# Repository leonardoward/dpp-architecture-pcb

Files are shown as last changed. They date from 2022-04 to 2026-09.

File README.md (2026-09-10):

# DPP Architecture Test Board v1.0

<p align="center">
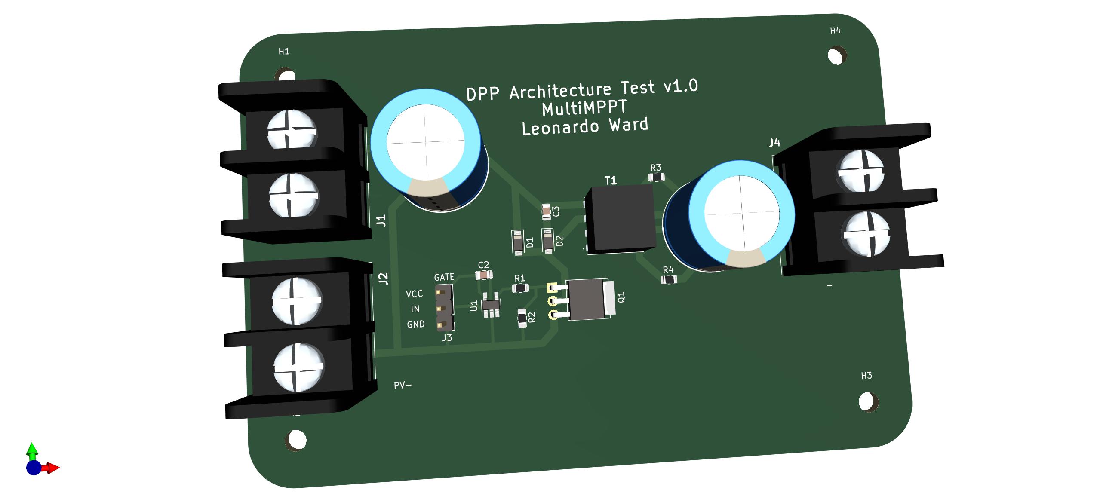
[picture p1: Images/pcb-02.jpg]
  
</p>

A single‑channel **isolated flyback power stage** on a KiCad 6 PCB, built to bench‑test
the converter used in a **Differential Power Processing (DPP)** MPPT. It is the hardware
side of the [**MultiMPPT**](https://hackaday.io/project/185092-multimppt) project &mdash; a
low‑cost, high‑efficiency MPPT with multiple independent inputs &mdash; and it implements
one converter cell from the model in
[`dpp-mppt-simulation`](https://github.com/leonardoward/dpp-mppt-simulation).

## Table of Contents

1. [What It Is](#what-it-is)
2. [How the Circuit Works](#how-the-circuit-works)
3. [Schematic](#schematic)
4. [Connectors](#connectors)
5. [Bill of Materials](#bill-of-materials)
6. [PCB](#pcb)
7. [Building the Board](#building-the-board)
8. [Repository Layout](#repository-layout)
9. [Notes & Safety](#notes--safety)
10. [License](#license)

## What It Is

In a DPP MPPT the PV modules stay in series to feed the load, and a small converter
across each module handles only the **difference** in current needed to hold that
module at its own maximum power point. This board is **one** of those converters,
broken out on its own so it can be driven, loaded and measured in isolation:

* PV / module side on `J1`, `J2`.
* String / bus side on `J4`, galvanically isolated through the transformer.
* The switching MOSFET is driven by an **external** controller (a microcontroller or a
  bench signal generator) through the 3‑pin gate‑driver header `J3` &mdash; there is no
  control loop, no sensing and no microcontroller on the board itself.

## How the Circuit Works

It is a classic isolated **flyback** converter:

1. **Input** &mdash; the module connects to `J1`/`J2`; `C1` (2200&nbsp;&micro;F) is the input
   bulk capacitor that holds the module voltage steady over a switching cycle.
2. **Switch** &mdash; `Q1` (IRFU120N N‑channel MOSFET) chops the current through the
   transformer primary. While `Q1` is on, energy is stored in the transformer core;
   when it turns off, that energy is delivered to the secondary.
3. **Gate drive** &mdash; the PWM signal enters on `J3` and is buffered by `U1`
   (DGD0215 gate driver) so the MOSFET can be switched cleanly at high frequency.
   `C2` (1&nbsp;&micro;F) decouples the driver, `R1` (1&nbsp;k) is the gate resistor and
   `R2` (100&nbsp;k) is the gate pull‑down that keeps `Q1` off when the drive is absent.
4. **Snubber / clamp** &mdash; `D1`, `D2` (1N4148W) with `C3` (47&nbsp;pF) form the
   protection network across the primary that absorbs the leakage‑inductance spike at
   turn‑off. The design allows populating either `D2 + C3` **or** `D1` alone.
5. **Transformer** &mdash; `T1` is a Würth **750311659** flyback transformer
   (180&nbsp;kHz, 1500&nbsp;Vrms primary‑to‑secondary isolation), which both transfers
   the energy and provides the galvanic isolation the DPP architecture needs.
6. **Output** &mdash; `C4` (2200&nbsp;&micro;F) filters the secondary and the converter
   output is brought out on `J4`. `R3`, `R4` are 0&nbsp;&Omega; jumpers / current‑sense
   footprints in the secondary return.

## Schematic

<p align="center">
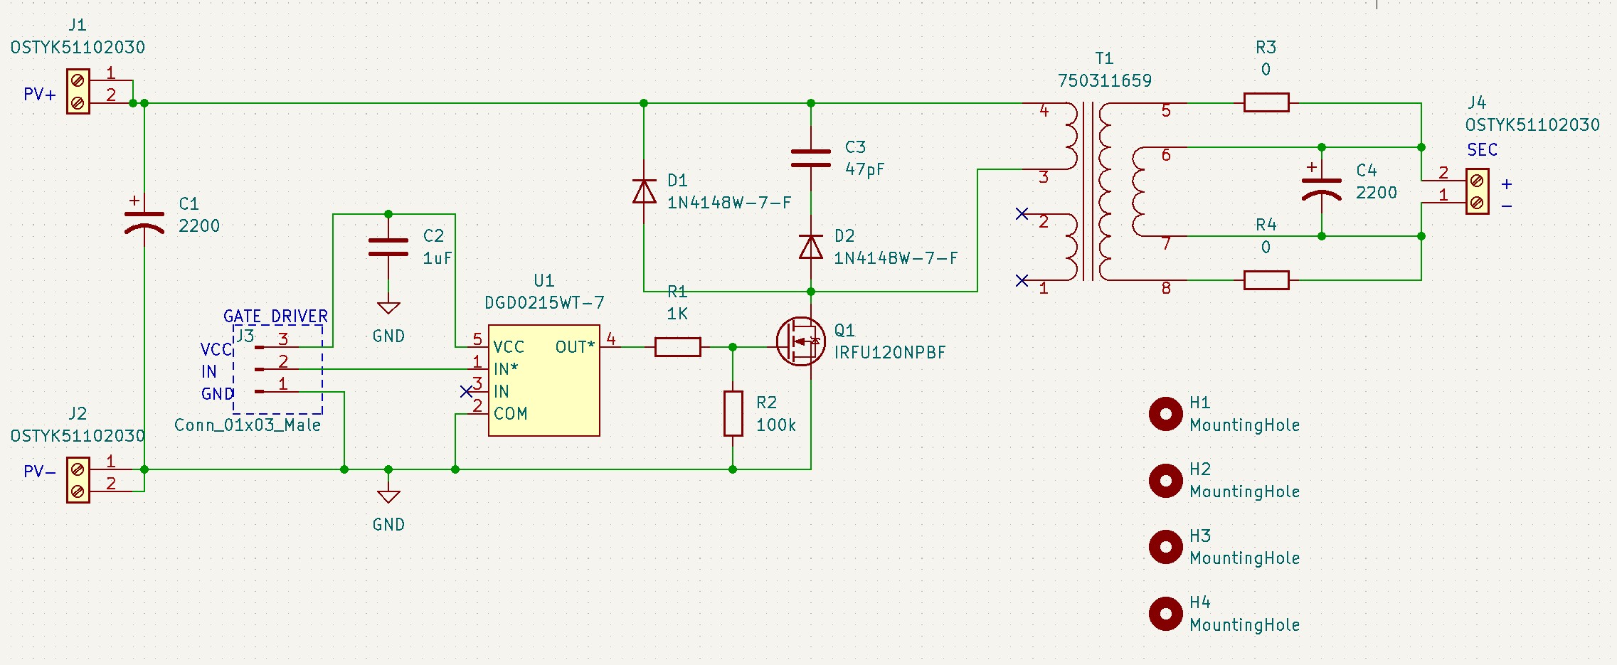
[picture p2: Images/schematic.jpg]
  
</p>

The full schematic is also in [`Schematic.pdf`](Schematic.pdf).

## Connectors

| Ref | Type | Purpose |
| --- | ---- | --- |
| `J1` | Barrier terminal block | `PV+` &mdash; module positive |
| `J2` | Barrier terminal block | `PV-` &mdash; module negative |
| `J3` | 3‑pin 0.1" header | Gate drive from the external controller: `VCC`, `IN`, `GND` |
| `J4` | Barrier terminal block | `SEC` &mdash; isolated secondary / string‑bus connection |
| `H1`&ndash;`H4` | Mounting holes | &mdash; |

## Bill of Materials

| Reference | Part | Qty |
| --- | ---- | --- |
| PCB | 2‑layer, [JLCPCB](https://jlcpcb.com/) | 1 |
| C1, C4 | 2200&nbsp;&micro;F 50&nbsp;V aluminium electrolytic, radial ([228CKS050MQW](https://www.digikey.com/en/products/detail/cornell-dubilier-illinois-capacitor/228CKS050MQW/5411846)) | 2 |
| C2 | 1&nbsp;&micro;F 25&nbsp;V X7R 0805 ([CL21B105KAFNNNE](https://www.digikey.com/en/products/detail/samsung-electro-mechanics/CL21B105KAFNNNE/3886724)) | 1 |
| C3 | 47&nbsp;pF 100&nbsp;V C0G/NP0 0805 ([08051A470JAT2A](https://www.digikey.com/en/products/detail/kyocera-avx/08051A470JAT2A/563392)) | 1 |
| D1, D2 | 100&nbsp;V 300&nbsp;mA SOD‑123 diode, 1N4148W ([1N4148W-7-F](https://www.digikey.com/en/products/detail/diodes-incorporated/1N4148W-7-F/814371)) | 2 |
| J1, J2, J4 | 9.50&nbsp;mm 2‑circuit barrier block ([OSTYK51102030](https://www.digikey.com/en/products/detail/on-shore-technology-inc/OSTYK51102030/1588818)) | 3 |
| Q1 | N‑channel 100&nbsp;V 9.4&nbsp;A IPAK / TO‑251, IRFU120N ([IRFU120NPBF](https://www.digikey.com/en/products/detail/infineon-technologies/IRFU120NPBF/812395)) | 1 |
| R1 | 1&nbsp;k&Omega; 1% 0805 ([RMCF0805FT1K00](https://www.digikey.com/en/products/detail/stackpole-electronics-inc/RMCF0805FT1K00/1760090)) | 1 |
| R2 | 100&nbsp;k&Omega; 1% 0805 ([RMCF0805FG100K](https://www.digikey.com/en/products/detail/stackpole-electronics-inc/RMCF0805FG100K/1712614)) | 1 |
| R3, R4 | 0&nbsp;&Omega; jumper 0805 ([RC0805JR-070RL](https://www.digikey.com/en/products/detail/yageo/RC0805JR-070RL/728216)) | 2 |
| T1 | Flyback transformer, 180&nbsp;kHz, 1500&nbsp;Vrms isolation, SMT ([750311659](https://www.digikey.com/en/products/detail/w%C3%BCrth-elektronik/750311659/4800066)) | 1 |
| U1 | Low‑side gate driver, inverting / non‑inverting, TSOT‑25 ([DGD0215WT-7](https://www.digikey.com/en/products/detail/diodes-incorporated/DGD0215WT-7/10130661)) | 1 |

A machine‑readable BOM is in [`dpp-architecture/dpp-architecture.csv`](dpp-architecture/dpp-architecture.csv).

## PCB

<p align="center">
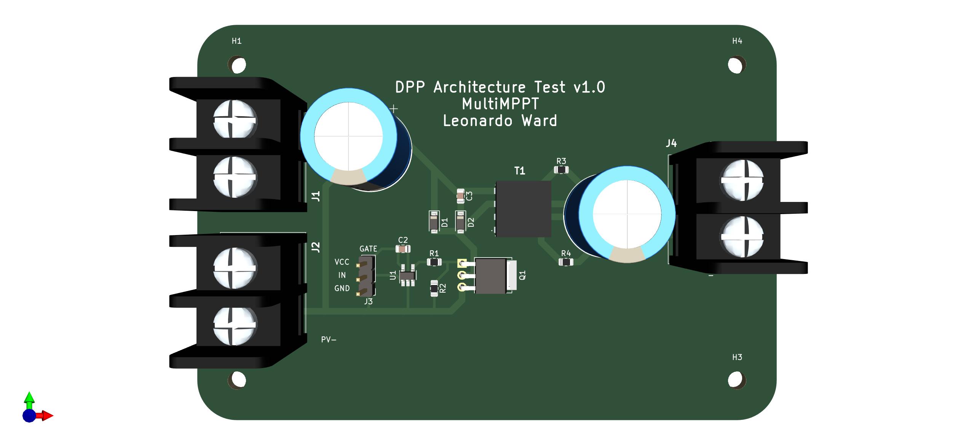
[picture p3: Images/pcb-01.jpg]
  
</p>

<p align="center">
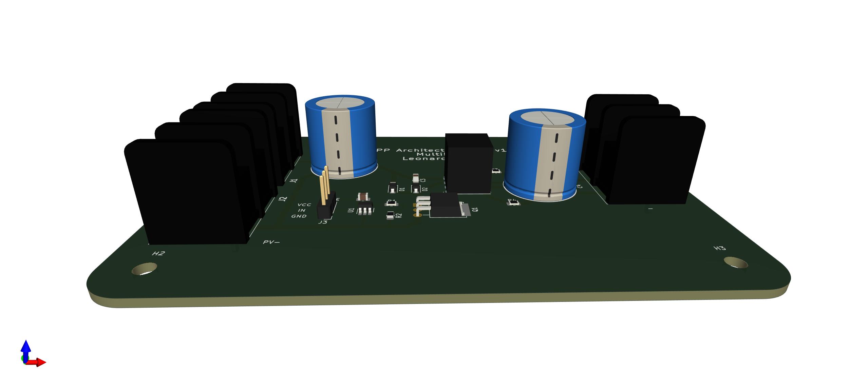
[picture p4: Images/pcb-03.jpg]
  
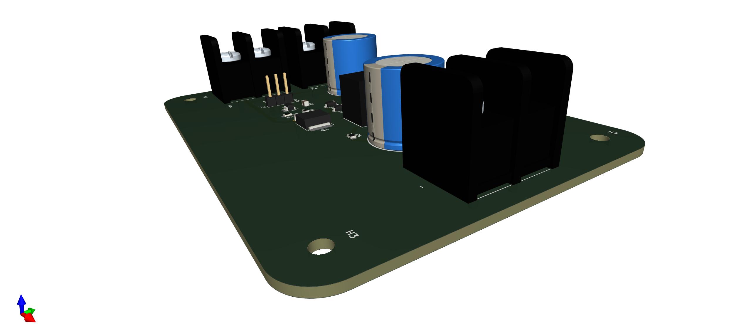
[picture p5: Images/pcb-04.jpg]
  
</p>

## Building the Board

* **Design files** &mdash; open `dpp-architecture/dpp-architecture.kicad_pro` in
  **KiCad 6** or newer. Project‑local symbol, footprint and 3D‑model libraries are
  under `dpp-architecture/Symbols/`, `dpp-architecture/Footprints/` and
  `dpp-architecture/3D/`.
* **Fabrication** &mdash; ready‑to‑send Gerbers and drill files are in
  `dpp-architecture/Gerber/` (and zipped as `dpp-architecture/Gerber.zip`); a step
  model of the assembly is in `dpp-architecture/Exports/`.

## Repository Layout

```
README.md                          this file
LICENSE                            GPL v3.0
Schematic.pdf                      exported schematic
Images/                            3D renders + schematic image for this README
dpp-architecture/
  dpp-architecture.kicad_pro/_sch/_pcb   KiCad 6 project
  dpp-architecture.csv               BOM
  Symbols/ Footprints/ 3D/           project-local libraries
  Gerber/  Gerber.zip                fabrication output
  Exports/                           STEP model of the board
  dpp-architecture-backups/          KiCad auto-save archive
```

## Notes & Safety

* This is a **v1.0 test fixture**, not a finished product: it exercises the power
  stage only. Closing the MPPT loop (sensing, duty‑cycle control) is done off‑board.
* The gate‑driver header exposes the drive rail; keep the external controller's ground
  common with `J3` `GND`.
* Electrolytic capacitors on both sides store charge &mdash; allow them to discharge
  before handling.
* The `dpp-architecture-backups/` folder is KiCad's auto‑save archive and is only kept
  for history; the working files are the ones directly under `dpp-architecture/`.

## License

Released under the **GNU General Public License v3.0** &mdash; see [`LICENSE`](LICENSE).

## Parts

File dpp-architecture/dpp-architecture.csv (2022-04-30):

Source: | /home/leonardow/Documents/dpp-architecture-pcb/dpp-architecture/dpp-architecture.kicad_sch
Date: | sáb 30 abr 2022 14:33:21
Tool: | Eeschema (6.0.4)
Generator: | /usr/share/kicad/plugins/bom_csv_grouped_by_value.py
Component Count: | 21
Individual Components:
Item | Qty | Reference(s) | Value | LibPart | Footprint | Datasheet | Description | Height | LCSC | Manufacturer | Manufacturer Part Number | Manufacturer_Name | Manufacturer_Part_Number | Supplier 1 | Supplier 2 | Supplier Part Number 1 | Supplier Part Number 2
 |  | C1 | 2200 | C-2200uF-50V-20%:2200 | Capacitor_THT:CP_Radial_D16.0mm_P7.50mm | https://www.cde.com/resources/catalogs/CKR_CKS.pdf |  |  |  |  |  | Cornell Dubilier / Illinois Capacitor | 228CKS050MQW | Digi-Key | Mouser | 228CKS050MQW-ND | 598-228CKS050MQW
 |  | C2 | 1uF | C-1uF-0805:1uF | Capacitor_SMD:C_0805_2012Metric | http://www.samsungsem.com/kr/support/product-search/mlcc/CL21B105KAFNNNE.jsp |  |  | C116352 | Samsung Electro-Mechanics | CL21B105KAFNNNE |  |  | Digi-Key | Mouser | 1276-1066-1-ND | 187-CL21B105KAFNNNE
 |  | C3 | 47pF | C-47pF-0805-100V-5%:47pF | Capacitor_SMD:C_0805_2012Metric | https://datasheets.kyocera-avx.com/C0GNP0-Dielectric.pdf |  |  |  | KYOCERA AVX |  |  | 08051A470JAT2A | Digi-Key | Mouser | 478-1282-1-ND | 581-08051A470J
 |  | C4 | 2200 | C-2200uF-50V-20%:2200 | Capacitor_THT:CP_Radial_D16.0mm_P7.50mm | https://www.cde.com/resources/catalogs/CKR_CKS.pdf |  |  |  |  |  | Cornell Dubilier / Illinois Capacitor | 228CKS050MQW | Digi-Key | Mouser | 228CKS050MQW-ND | 598-228CKS050MQW
 |  | D1 | 1N4148W-7-F | D-1N4148W-7-F:1N4148W-7-F | Diode_SMD:D_SOD-123 | https://www.diodes.com/assets/Datasheets/BAV16W_1N4148W.pdf |  |  | C83528 |  |  | Diodes Incorporated | 1N4148W-7-F | Digi-Key | Mouser | 1N4148W-FDICT-ND | 621-1N4148W-F
 |  | D2 | 1N4148W-7-F | D-1N4148W-7-F:1N4148W-7-F | Diode_SMD:D_SOD-123 | https://www.diodes.com/assets/Datasheets/BAV16W_1N4148W.pdf |  |  | C83528 |  |  | Diodes Incorporated | 1N4148W-7-F | Digi-Key | Mouser | 1N4148W-FDICT-ND | 621-1N4148W-F
 |  | H1 | MountingHole | Mechanical:MountingHole | MountingHole:MountingHole_3.5mm | ~
 |  | H2 | MountingHole | Mechanical:MountingHole | MountingHole:MountingHole_3.5mm | ~
 |  | H3 | MountingHole | Mechanical:MountingHole | MountingHole:MountingHole_3.5mm | ~
 |  | H4 | MountingHole | Mechanical:MountingHole | MountingHole:MountingHole_3.5mm | ~
 |  | J1 | OSTYK51102030 | J-OSTYK51102030:OSTYK51102030 | J-OSTYK51102030:OSTYK51102030 | https://datasheet.datasheetarchive.com/originals/distributors/Datasheets-DGA23/1525676.pdf | CONN BARRIER STRIP 2CIRC 0.374" | 18.5 |  |  |  | On Shore Technology Inc. | OSTYK51102030 | Digi-Key |  | ED2953-ND
 |  | J2 | OSTYK51102030 | J-OSTYK51102030:OSTYK51102030 | J-OSTYK51102030:OSTYK51102030 | https://datasheet.datasheetarchive.com/originals/distributors/Datasheets-DGA23/1525676.pdf | CONN BARRIER STRIP 2CIRC 0.374" | 18.5 |  |  |  | On Shore Technology Inc. | OSTYK51102030 | Digi-Key |  | ED2953-ND
 |  | J3 | Conn_01x03_Male | Connector:Conn_01x03_Male | Connector_PinHeader_2.54mm:PinHeader_1x03_P2.54mm_Vertical | ~
 |  | J4 | OSTYK51102030 | J-OSTYK51102030:OSTYK51102030 | J-OSTYK51102030:OSTYK51102030 | https://datasheet.datasheetarchive.com/originals/distributors/Datasheets-DGA23/1525676.pdf | CONN BARRIER STRIP 2CIRC 0.374" | 18.5 |  |  |  | On Shore Technology Inc. | OSTYK51102030 | Digi-Key |  | ED2953-ND
 |  | Q1 | IRFU120NPBF | Q-IRFU120NPBF:IRFU120NPBF | Package_TO_SOT_THT:TO-251-3-1EP_Horizontal_TabDown | https://www.infineon.com/dgdl/irfr120npbf.pdf?fileId=5546d462533600a40153562d2620204d |  |  | C3025 |  |  | Infineon Technologies | IRFU120NPBF | Digi-Key | Mouser | IRFU120NPBF-ND | 942-IRFU120NPBF
 |  | R1 | 1K | R-1K-0805:1K | Resistor_SMD:R_0805_2012Metric | https://www.seielect.com/catalog/sei-rmcf_rmcp.pdf |  |  |  | Stackpole Electronics Inc |  |  | RMCF0805FT1K00 | Digi-Key |  | RMCF0805FT1K00CT-ND
 |  | R2 | 100k | R-100K-0805:100k | Resistor_SMD:R_0805_2012Metric_Pad1.20x1.40mm_HandSolder | https://www.seielect.com/catalog/sei-rmcf_rmcp.pdf |  |  |  |  |  | Stackpole Electronics Inc | RMCF0805FG100K | Digi-Key |  | RMCF0805FG100KCT-ND
 |  | R3 | 0 | R-0-0805:0 | Resistor_SMD:R_0805_2012Metric | https://www.yageo.com/upload/media/product/productsearch/datasheet/rchip/PYu-RC_Group_51_RoHS_L_11.pdf |  |  |  | Yageo | RC0805JR-070RL |  |  | Digi-Key |  | 311-0.0ARCT-ND
 |  | R4 | 0 | R-0-0805:0 | Resistor_SMD:R_0805_2012Metric | https://www.yageo.com/upload/media/product/productsearch/datasheet/rchip/PYu-RC_Group_51_RoHS_L_11.pdf |  |  |  | Yageo | RC0805JR-070RL |  |  | Digi-Key |  | 311-0.0ARCT-ND
 |  | T1 | 750311659 | T-750311659:750311659 | T-750311659:750311659 | https://katalog.we-online.de/ctm/datasheet/750311659.pdf | Power Transformers MID-L8300 LT Flyback Isol .3mH 5V .08A | 10.54 |  |  |  | Wurth Elektronik | 750311659 | Digi-Key | Mouser | 1297-1126-1-ND | 710-750311659
 |  | U1 | DGD0215WT-7 | U-DGD0215WT-7:DGD0215WT-7 | Package_TO_SOT_SMD:SOT-23-5_HandSoldering | https://www.diodes.com/assets/Datasheets/DGD0215-0216.pdf |  |  |  |  |  | Diodes Incorporated | DGD0215WT-7 | Digi-Key |  | DGD0215WT-7DICT-ND
Collated Components:
Item | Qty | Reference(s) | Value | LibPart | Footprint | Datasheet | Description | Height | LCSC | Manufacturer | Manufacturer Part Number | Manufacturer_Name | Manufacturer_Part_Number | Supplier 1 | Supplier 2 | Supplier Part Number 1 | Supplier Part Number 2
1 | 2 | C1, C4 | 2200 | C-2200uF-50V-20%:2200 | Capacitor_THT:CP_Radial_D16.0mm_P7.50mm | https://www.cde.com/resources/catalogs/CKR_CKS.pdf |  |  |  |  |  | Cornell Dubilier / Illinois Capacitor | 228CKS050MQW | Digi-Key | Mouser | 228CKS050MQW-ND | 598-228CKS050MQW
2 | 1 | C2 | 1uF | C-1uF-0805:1uF | Capacitor_SMD:C_0805_2012Metric | http://www.samsungsem.com/kr/support/product-search/mlcc/CL21B105KAFNNNE.jsp |  |  | C116352 | Samsung Electro-Mechanics | CL21B105KAFNNNE |  |  | Digi-Key | Mouser | 1276-1066-1-ND | 187-CL21B105KAFNNNE
3 | 1 | C3 | 47pF | C-47pF-0805-100V-5%:47pF | Capacitor_SMD:C_0805_2012Metric | https://datasheets.kyocera-avx.com/C0GNP0-Dielectric.pdf |  |  |  | KYOCERA AVX |  |  | 08051A470JAT2A | Digi-Key | Mouser | 478-1282-1-ND | 581-08051A470J
4 | 2 | D1, D2 | 1N4148W-7-F | D-1N4148W-7-F:1N4148W-7-F | Diode_SMD:D_SOD-123 | https://www.diodes.com/assets/Datasheets/BAV16W_1N4148W.pdf |  |  | C83528 |  |  | Diodes Incorporated | 1N4148W-7-F | Digi-Key | Mouser | 1N4148W-FDICT-ND | 621-1N4148W-F
5 | 4 | H1, H2, H3, H4 | MountingHole | Mechanical:MountingHole | MountingHole:MountingHole_3.5mm | ~
6 | 3 | J1, J2, J4 | OSTYK51102030 | J-OSTYK51102030:OSTYK51102030 | J-OSTYK51102030:OSTYK51102030 | https://datasheet.datasheetarchive.com/originals/distributors/Datasheets-DGA23/1525676.pdf | CONN BARRIER STRIP 2CIRC 0.374" | 18.5 |  |  |  | On Shore Technology Inc. | OSTYK51102030 | Digi-Key |  | ED2953-ND
7 | 1 | J3 | Conn_01x03_Male | Connector:Conn_01x03_Male | Connector_PinHeader_2.54mm:PinHeader_1x03_P2.54mm_Vertical | ~
8 | 1 | Q1 | IRFU120NPBF | Q-IRFU120NPBF:IRFU120NPBF | Package_TO_SOT_THT:TO-251-3-1EP_Horizontal_TabDown | https://www.infineon.com/dgdl/irfr120npbf.pdf?fileId=5546d462533600a40153562d2620204d |  |  | C3025 |  |  | Infineon Technologies | IRFU120NPBF | Digi-Key | Mouser | IRFU120NPBF-ND | 942-IRFU120NPBF
9 | 1 | R1 | 1K | R-1K-0805:1K | Resistor_SMD:R_0805_2012Metric | https://www.seielect.com/catalog/sei-rmcf_rmcp.pdf |  |  |  | Stackpole Electronics Inc |  |  | RMCF0805FT1K00 | Digi-Key |  | RMCF0805FT1K00CT-ND
10 | 1 | R2 | 100k | R-100K-0805:100k | Resistor_SMD:R_0805_2012Metric_Pad1.20x1.40mm_HandSolder | https://www.seielect.com/catalog/sei-rmcf_rmcp.pdf |  |  |  |  |  | Stackpole Electronics Inc | RMCF0805FG100K | Digi-Key |  | RMCF0805FG100KCT-ND
11 | 2 | R3, R4 | 0 | R-0-0805:0 | Resistor_SMD:R_0805_2012Metric | https://www.yageo.com/upload/media/product/productsearch/datasheet/rchip/PYu-RC_Group_51_RoHS_L_11.pdf |  |  |  | Yageo | RC0805JR-070RL |  |  | Digi-Key |  | 311-0.0ARCT-ND
12 | 1 | T1 | 750311659 | T-750311659:750311659 | T-750311659:750311659 | https://katalog.we-online.de/ctm/datasheet/750311659.pdf | Power Transformers MID-L8300 LT Flyback Isol .3mH 5V .08A | 10.54 |  |  |  | Wurth Elektronik | 750311659 | Digi-Key | Mouser | 1297-1126-1-ND | 710-750311659
13 | 1 | U1 | DGD0215WT-7 | U-DGD0215WT-7:DGD0215WT-7 | Package_TO_SOT_SMD:SOT-23-5_HandSoldering | https://www.diodes.com/assets/Datasheets/DGD0215-0216.pdf |  |  |  |  |  | Diodes Incorporated | DGD0215WT-7 | Digi-Key |  | DGD0215WT-7DICT-ND

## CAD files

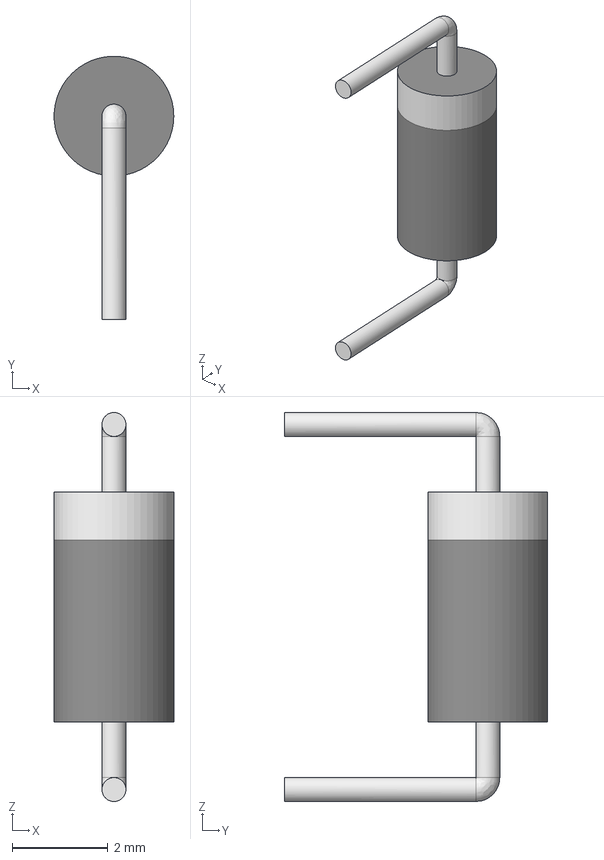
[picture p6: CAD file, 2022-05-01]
dpp-architecture/3D/Diode.stp
2.50 x 5.50 x 8.12 mm

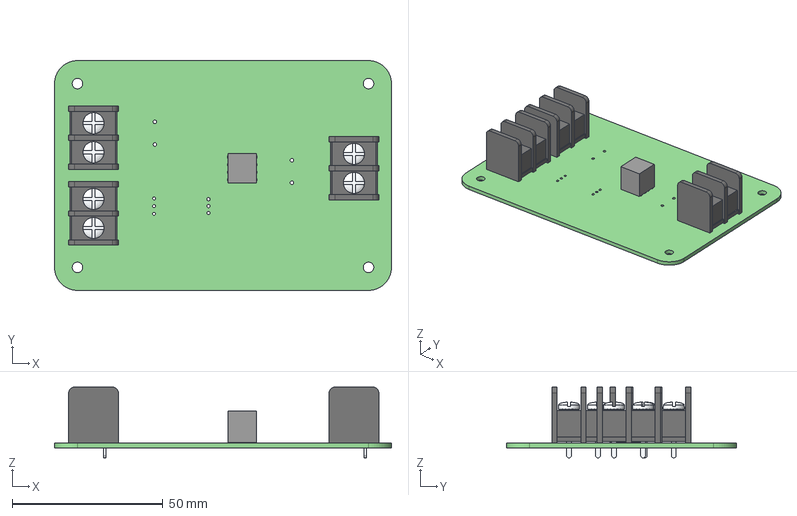
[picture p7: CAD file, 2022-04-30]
dpp-architecture/Exports/DPP-Architecture-PCB.step
111.8 x 76.2 x 23.5 mm
dpp-architecture PCB

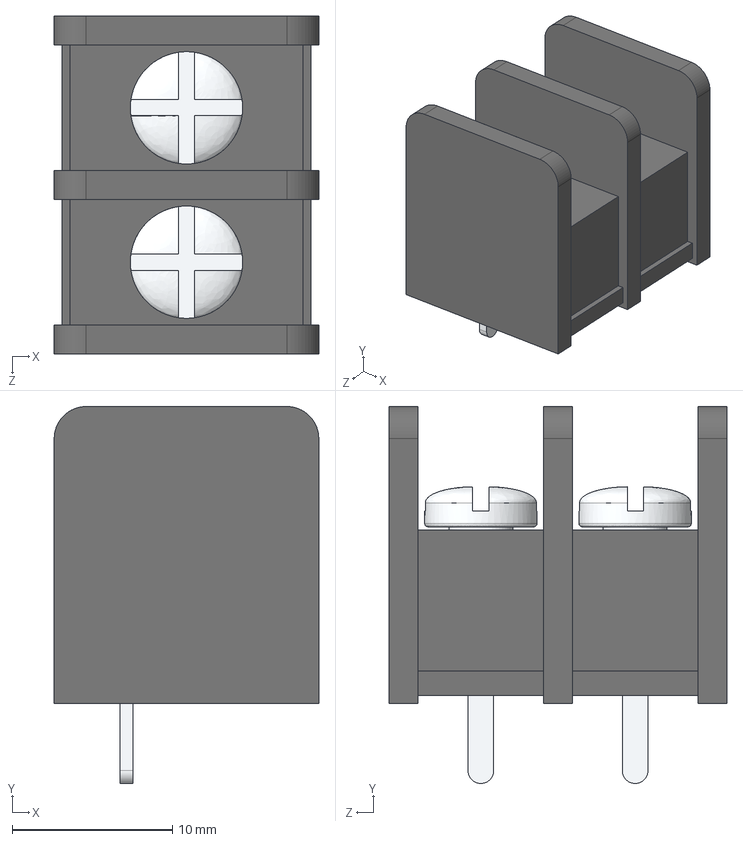
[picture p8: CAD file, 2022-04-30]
dpp-architecture/3D/Barrier Terminal Block 95mm 2-Pins.STEP
16.5 x 23.5 x 21.1 mm

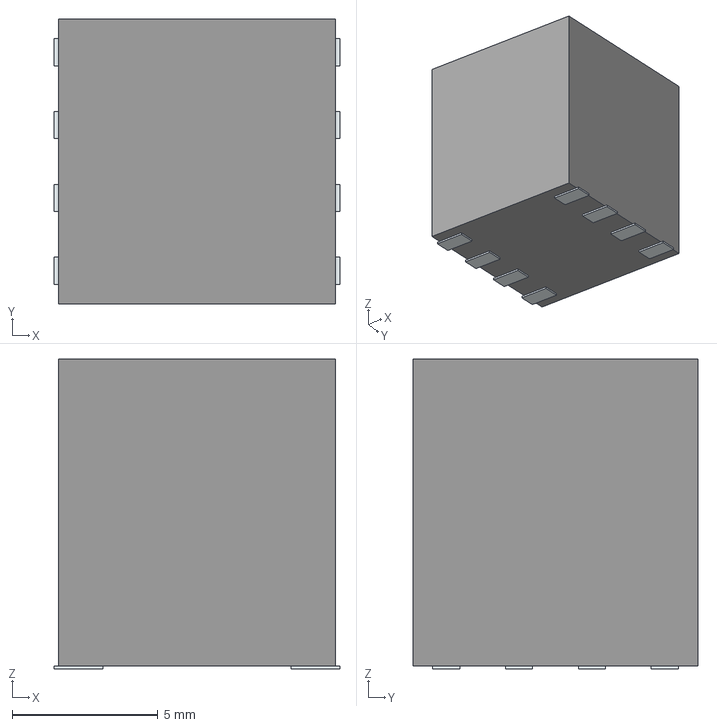
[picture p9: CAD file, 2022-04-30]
dpp-architecture/3D/750311659.stp
9.81 x 9.78 x 10.6 mm
Pins

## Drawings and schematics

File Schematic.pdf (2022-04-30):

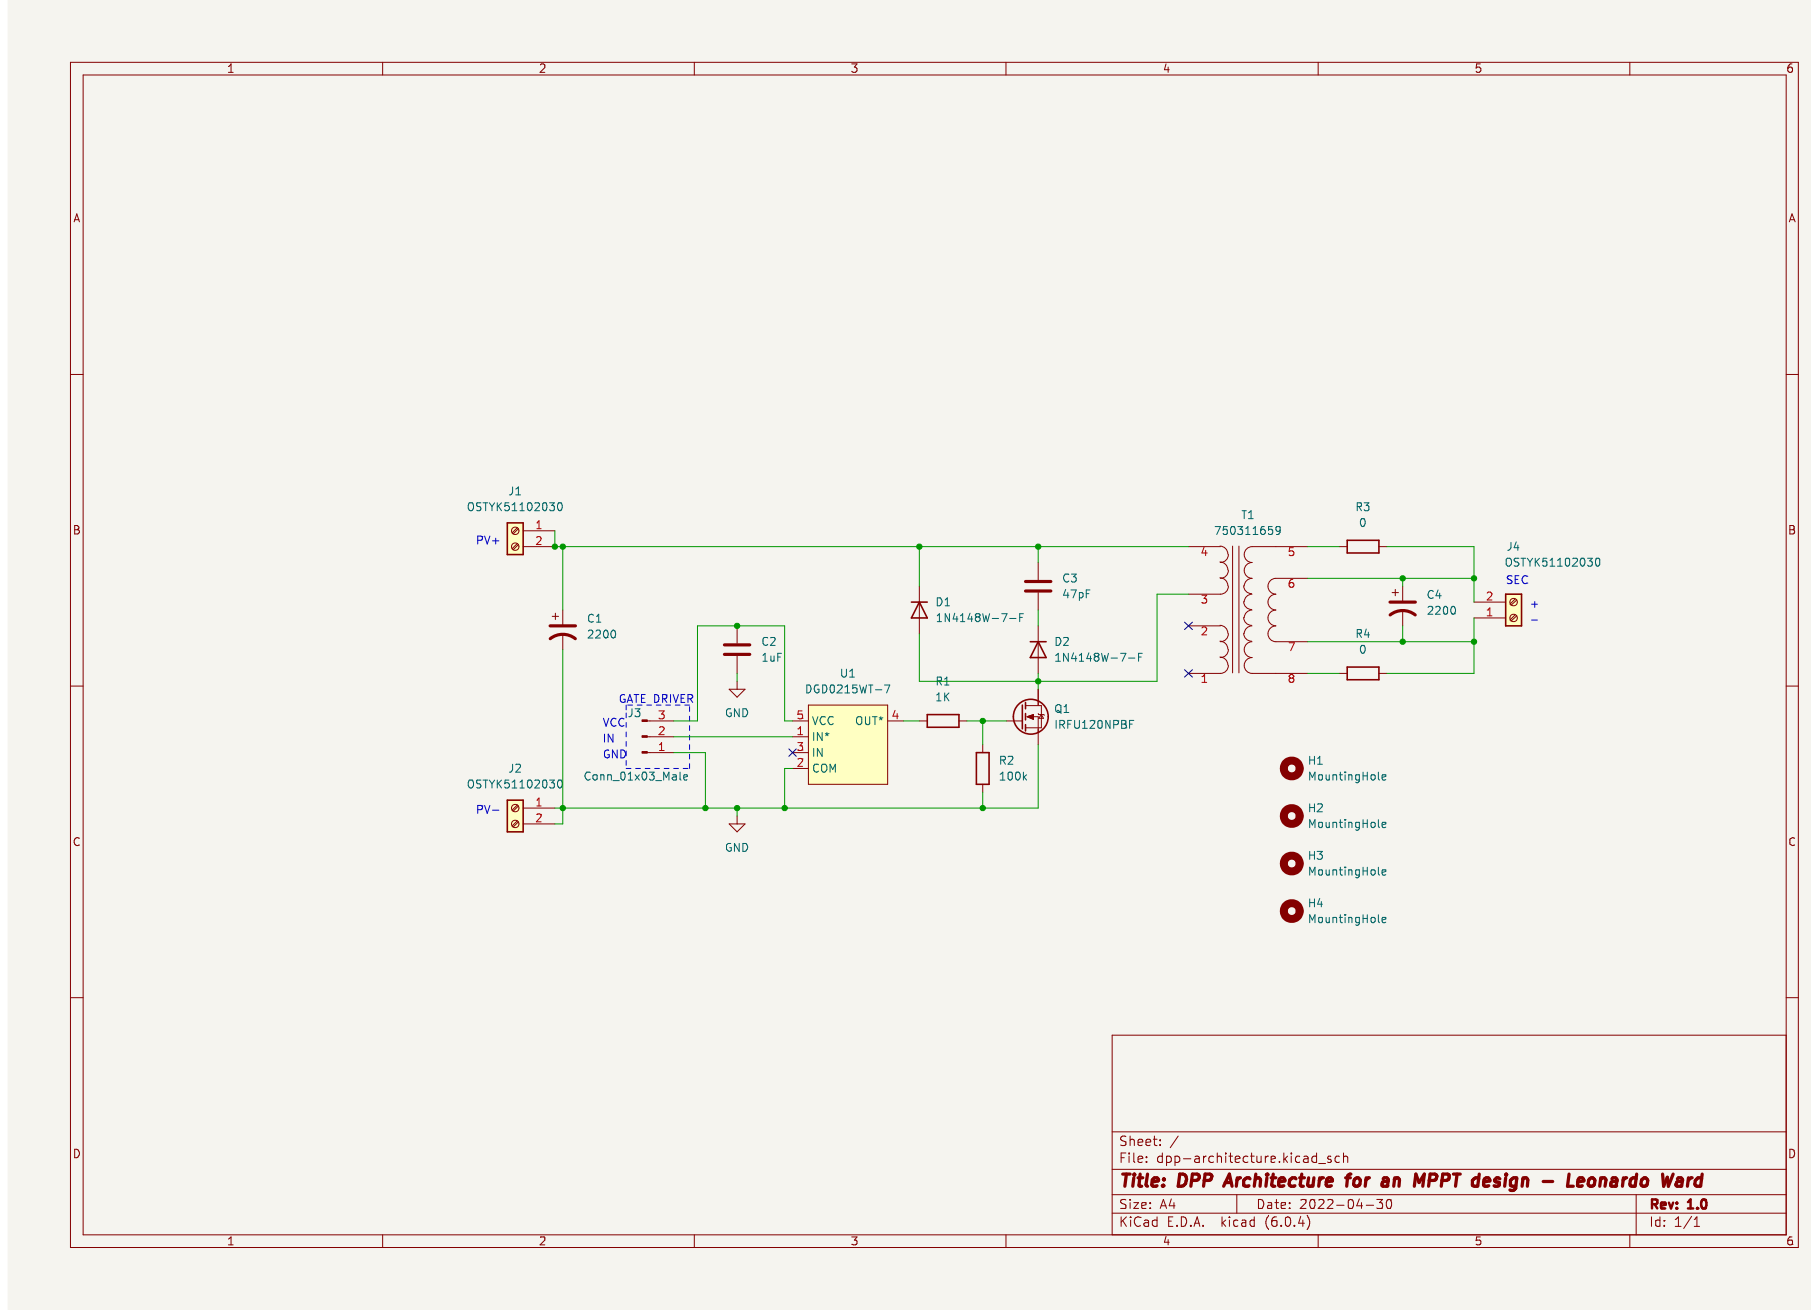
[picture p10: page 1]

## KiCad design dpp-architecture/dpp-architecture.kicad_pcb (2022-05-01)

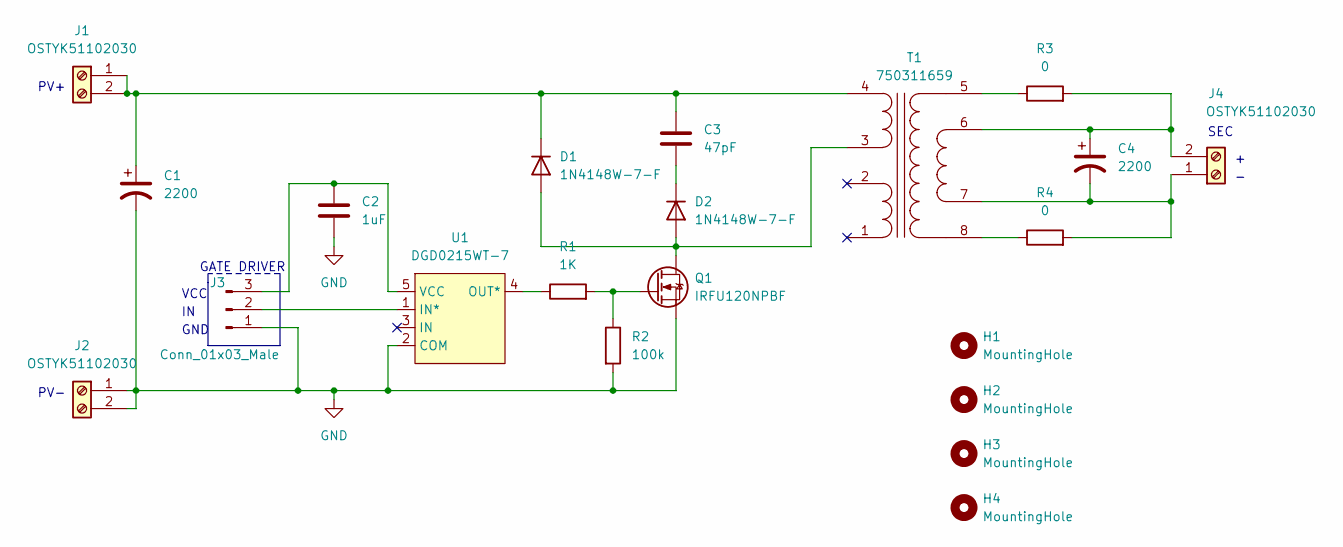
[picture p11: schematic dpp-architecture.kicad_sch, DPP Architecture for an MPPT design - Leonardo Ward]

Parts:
C1, C4: 2200; CP_Radial_D16.0mm_P7.50mm; Manufacturer_Part_Number 228CKS050MQW
C2: 1uF; C_0805_2012Metric; Manufacturer Part Number CL21B105KAFNNNE; LCSC C116352
C3: 47pF; C_0805_2012Metric; Manufacturer_Part_Number 08051A470JAT2A
D1, D2: 1N4148W-7-F; D_SOD-123; Manufacturer_Part_Number 1N4148W-7-F; LCSC C83528
H1, H2, H3, H4: MountingHole; MountingHole_3.5mm
J1, J2, J4: OSTYK51102030; Manufacturer_Part_Number OSTYK51102030
J3: Conn_01x03_Male; PinHeader_1x03_P2.54mm_Vertical
Q1: IRFU120NPBF; TO-251-3-1EP_Horizontal_TabDown; Manufacturer_Part_Number IRFU120NPBF; LCSC C3025
R1: 1K; R_0805_2012Metric; Manufacturer_Part_Number RMCF0805FT1K00
R2: 100k; R_0805_2012Metric_Pad1.20x1.40mm_HandSolder; Manufacturer_Part_Number RMCF0805FG100K
R3, R4: 0; R_0805_2012Metric; Manufacturer Part Number RC0805JR-070RL
T1: 750311659; Manufacturer_Part_Number 750311659
U1: DGD0215WT-7; SOT-23-5_HandSoldering; Manufacturer_Part_Number DGD0215WT-7

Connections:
GND: C1.2, C2.2, J2.1, J2.2, J3.1, Q1.3 (S), R2.2, U1.2 (COM)
unnamed: C1.1, C3.1, D1.1 (K), J1.1, J1.2, T1.4 (PRI_2)
unnamed: C2.1, J3.3, U1.5 (VCC)
unnamed: C3.2, D2.1 (K)
unnamed: C4.1, J4.2, R3.2, T1.6 (SEC_2)
unnamed: C4.2, J4.1, R4.2, T1.7 (SEC_3)
unnamed: D1.2 (A), D2.2 (A), Q1.2 (D), Q1.4 (D), T1.3 (PRI_1)
unnamed: J3.2, U1.1 (IN*)
unnamed: Q1.1 (G), R1.2, R2.1
unnamed: R1.1, U1.4 (OUT*)
unnamed: R3.1, T1.5 (SEC_1)
unnamed: R4.1, T1.8 (SEC_4)

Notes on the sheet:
VCC
SEC
PV+
GND
PV-
GATE DRIVER

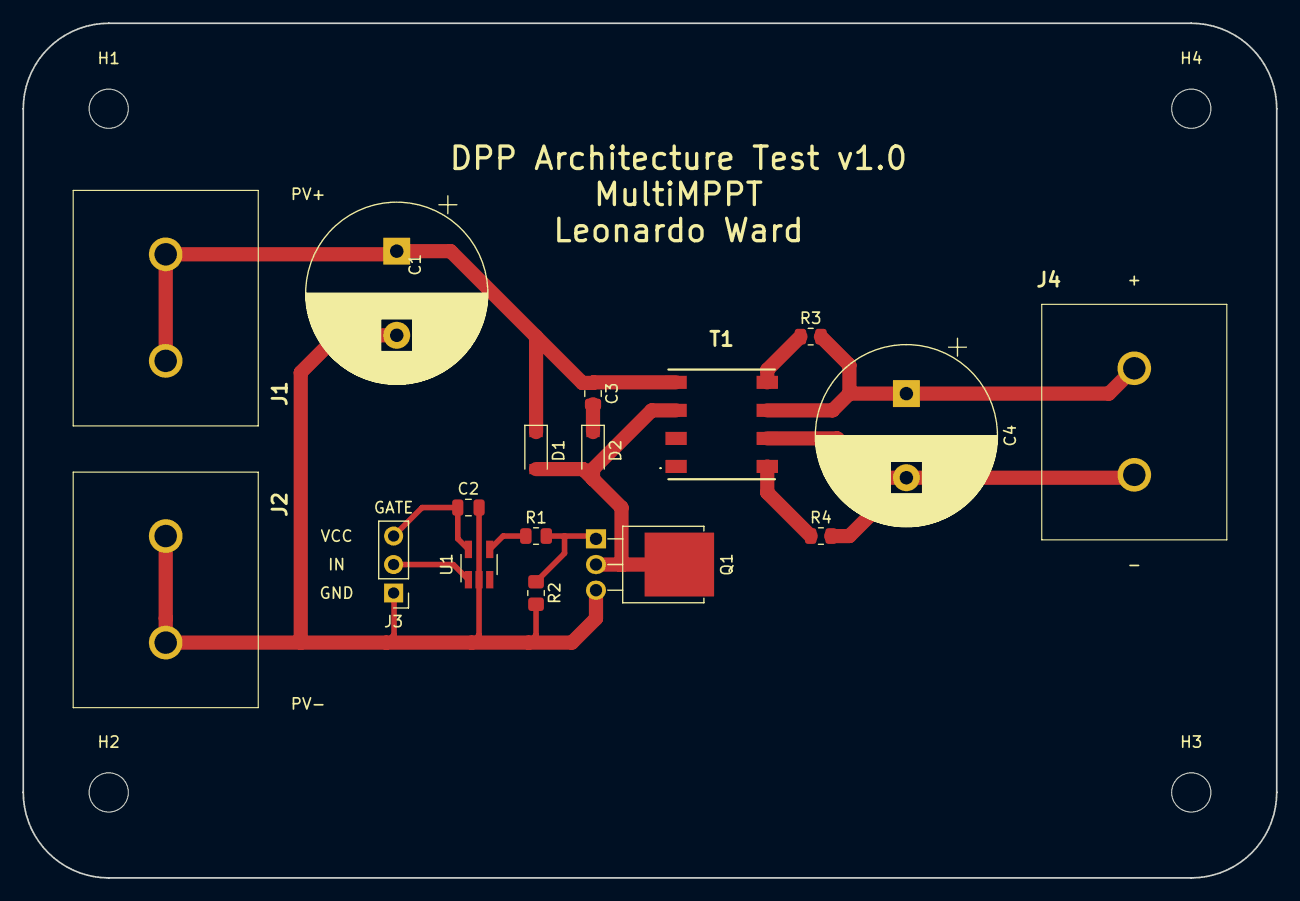
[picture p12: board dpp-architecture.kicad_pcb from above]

Board: 2 copper layers, 111.8 x 76.2 mm, 21 parts (0 on the bottom side), 12 nets.

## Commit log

2022-04-28 Added Kicad 6 project
    [dpp-architecture.kicad_pcb, dpp-architecture.kicad_sch]
2022-04-29 Added kicad project, transformer and terminal blocks
    [dpp-architecture.kicad_sch]
2022-04-29 Added mosfet, primary and secondary capacitors and a snubber capacitor
    [dpp-architecture.kicad_sch]
2022-04-30 Finished schematic and pcb routing, created images of the 3D model
    [750311659.stp, Barrier Terminal Block 95mm 2-Pins.STEP, dpp-architecture.kicad_pcb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]
2022-04-30 Added 3D Model (step file)
    [dpp-architecture-pcb.step]
2022-04-30 Added documentation to the readme: images of the schematic, pcb and added bill of materials
    [dpp-architecture.csv, dpp-architecture.kicad_pcb]
2022-04-30 Added schematic and small fixes
    [DPP-Architecture-PCB.step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]
2022-05-01 Added 3D Models
    [Diode.stp, dpp-architecture.kicad_pcb]
2022-05-01 Added gerber files
